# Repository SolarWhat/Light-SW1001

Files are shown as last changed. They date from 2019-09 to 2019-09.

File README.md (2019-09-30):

# Light-SW1001

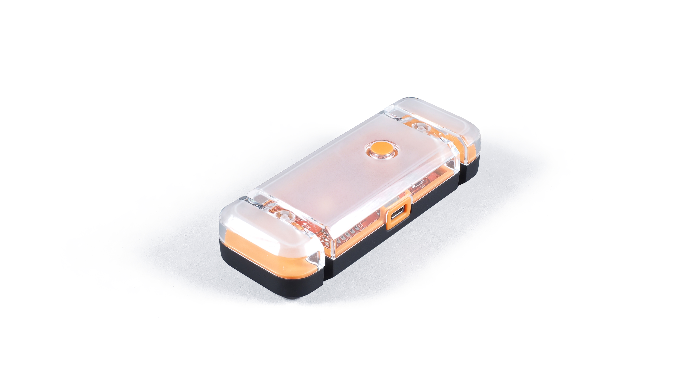
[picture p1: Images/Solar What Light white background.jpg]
Solar What Light Hero Image


Solar What?! is the outcome of ongoing research at the University of Edinburgh.

The product design process has taken place over three continents, with input from solar technicians, end users and energy access practitioners.

In 2017 over 6 million small, solar powered lighting devices were sold worldwide and 1.6 million solar powered lighting devices entered electronic waste flows.

We believe that delivering affordable, clean energy for all can also promote responsible production and consumption.

Our goal is to advocate for sustainable design in the global solar industry and promote the repair, reuse and recycling of solar powered electronics. We are pro-solar, anti-waste.

The Solar What?! Power is one of two products we have designed to champion our research and catalyse discussion around sustainability and repairability in the off-grid solar sector. The repository for our other product, the Solar What Power, can be found [here](https://github.com/SolarWhat/Power-SW2001 "here").

We encourage you to download the files, reproduce the products, make edits, suggest improvements and, most importantly, share your ideas around design for sustainable international development.  

More information about the project and the team behind it can be found on our [website](http://www.solarwhat.xyz/index.php "website").

You can get in touch with the team by emailing info@solarwhat.xyz. 

[User Manual and Tech Specs](http://www.solarwhat.xyz/resources.php "User Manual and Tech Specs")

[Gerber Files, BOM and Firmware Files](https://github.com/SolarWhat/Light-SW1001/tree/master/PCB%20Files "Gerber Files, BOM and Firmware Files")

[CAD Files (stp)](https://github.com/SolarWhat/Light-SW1001/blob/master/Solar%20What%20Light%20Assembly.stp "CAD Files (stp)")

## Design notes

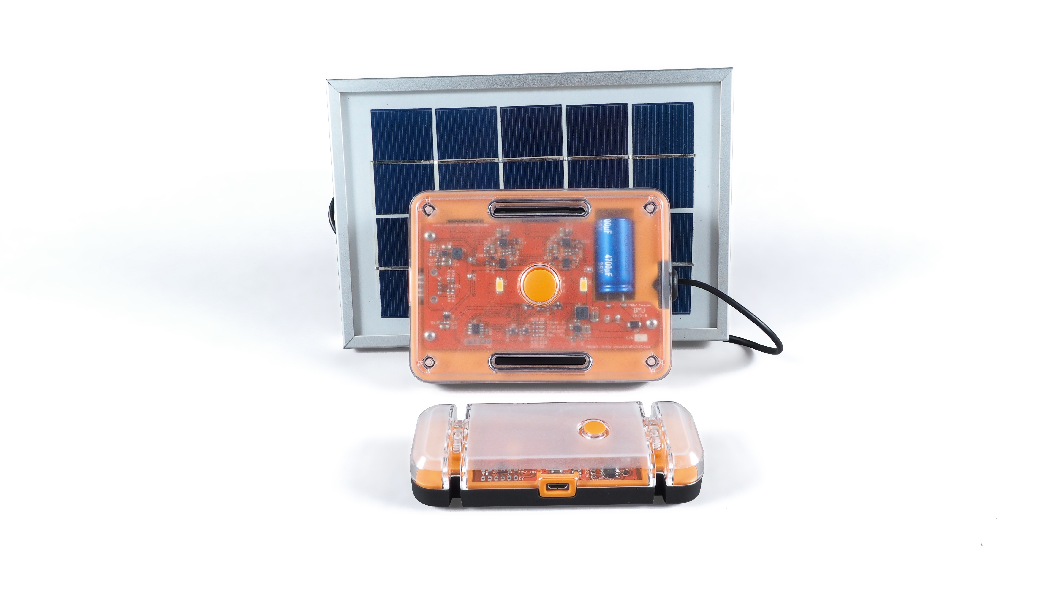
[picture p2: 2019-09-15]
Images/Solar What hero image (both).jpg

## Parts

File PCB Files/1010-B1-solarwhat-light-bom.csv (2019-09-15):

WARNING: This file is auto-generated from schematic, do not edit manually!
Component | Value | Manufacturer Part Number | Supplier Part Number | Description | Notes
C1 | 1206-10U-35V 10u 35V | 1206 10uF 35V 10% X7R | standard
C2 | 1206-10U-35V 10u 35V | 1206 10uF 35V 10% X7R | standard
C3 | 1206-10U-35V 10u 35V | 1206 10uF 35V 10% X7R | standard
C4 | 0603-100N 100n | 0603 100nF 50V 10% X7R | standard
C5 | 0603-100N 100n | 0603 100nF 50V 10% X7R | standard
D1 |  | Cree JB5630AWT-C0-0000-000A0UC430E | Farnell 2853292
D2 |  | 0603 orange | Farnell 2687484
D3 |  | 0603 green | Farnell 2687486
D4 |  | Nexperia BZX84-A3V3 | Farnell 2463632
D5 |  | 0603 red | Farnell 2687488
J1 |  | Molex 10544301-1101 | Farnell 2500017
J2 |  | AVX 009155003301006 | Digi-key 478-4687-1-ND
J3 |  | PIC-ICSP-TH-RA PIC-ICSP-TH-RA |  |  | Do not populate
J4 |  | PINHEAD-2-SQUARE PINHEAD-2-SQUARE |  |  | Do not populate
JP1 |  | SOLDER-JUMPER-1MM-SQUARE SOLDER-JUMPER-1-1 |  |  | Bridge
JP2 |  | SOLDER-JUMPER-1MM-SQUARE SOLDER-JUMPER-1-1 |  |  | Do not populate
JP3 |  | SOLDER-JUMPER-1MM-SQUARE SOLDER-JUMPER-1-1 |  |  | Do not populate
Q1 |  | Diodes Inc DMP2035U | Farnell 2061419
Q2 |  | Diodes Inc DMP2035U | Farnell 2061419
Q3 |  | Diodes Inc DMP2035U | Farnell 2061419
R1 | 0603-1%-330R 330R | 0603 330R 1% 100mW | standard
R2 | 0603-1%-330R 330R | 0603 330R 1% 100mW | standard
R3 | 0603-1%-3K9 3K9 | 0603 3K9 1% 100mW | standard
R4 | 0603-1%-22K 22K | 0603 22K 1% 100mW | standard
R5 | 0603-1%-22K 22K | 0603 22K 1% 100mW | standard
R6 | 0603-1%-100K 100K | 0603 100K 1% 100mW | standard
R7 | 0603-1%-680K 680K | 0603 680K 1% 100mW | standard
R8 | 0603-1%-1M 1M | 0603 1M 1% 100mW | standard
R9 | 0603-1%-1M 1M | 0603 1M 1% 100mW | standard
R10 | 0603-1%-100K 100K | 0603 100K 1% 100mW | standard
R11 | 0603-1%-1M 1M | 0603 1M 1% 100mW | standard
R12 | 0805-1%-17R6 17R6 | 0805 17R8 1% 100mW | Farnell 2303354
R13 | 0805-1%-1R15 1R15 | 0805 1R15 1% 100mW | Farnell 2141631
R14 | 0603-1%-20K 20K | 0603 20K 1% 100mW | standard
R15 | 0603-1%-5K23 5K23 | 0603 5K23 1% 100mW | standard
R16 | 0603-1%-7K5 7K5 | 0603 7K5 1% 100mW | standard
R17 | 0603-1%-330R 330R | 0603 330R 1% 100mW | standard
R18 | 0603-1%-330R 330R | 0603 330R 1% 100mW | standard
SW1 |  | Alcoswitch FSM4JSMA | Farnell 3801305
U1 |  | Microchip MCP73831T-2ACI/OT | Farnell 1332158
U2 |  | Maxim MAX6775XKB+T | Farnell 2799268
U3 |  | Microchip MCP1824T-ADJE/OT | Farnell 1578393
U5 |  | TI LMT87DCKR | Farnell 2782528
U6 |  | TI LM358ADR | Farnell 7527007
U7 |  | On Semi MC74VHC1GT00DF | Farnell 2724115
U8 |  | Microchip PIC12F1571-I/SN | Farnell 2419682

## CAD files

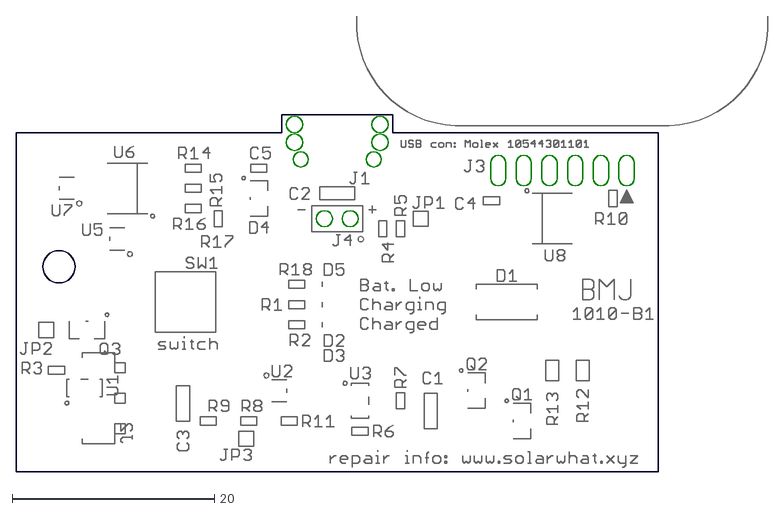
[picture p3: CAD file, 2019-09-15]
PCB Files/1010-B1-solarwhat-light-dimensions.dxf
74.3 x 45.0

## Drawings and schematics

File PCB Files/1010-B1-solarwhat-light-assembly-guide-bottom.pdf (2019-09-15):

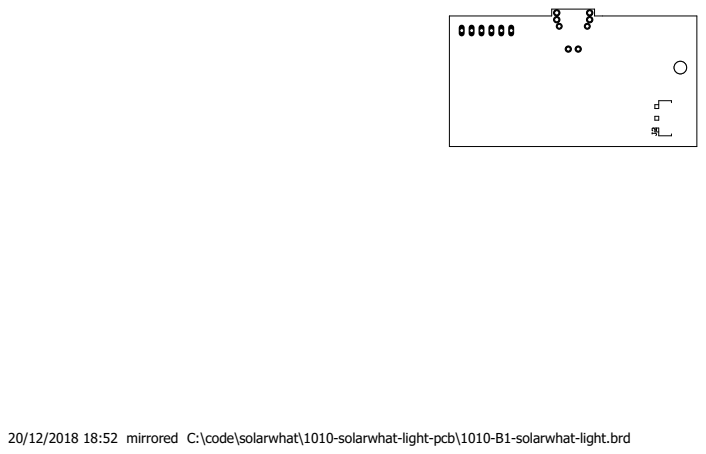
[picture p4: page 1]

20/12/2018 18:52 mirrored C:\code\solarwhat\1010-solarwhat-light-pcb\1010-B1-solarwhat-light.brd

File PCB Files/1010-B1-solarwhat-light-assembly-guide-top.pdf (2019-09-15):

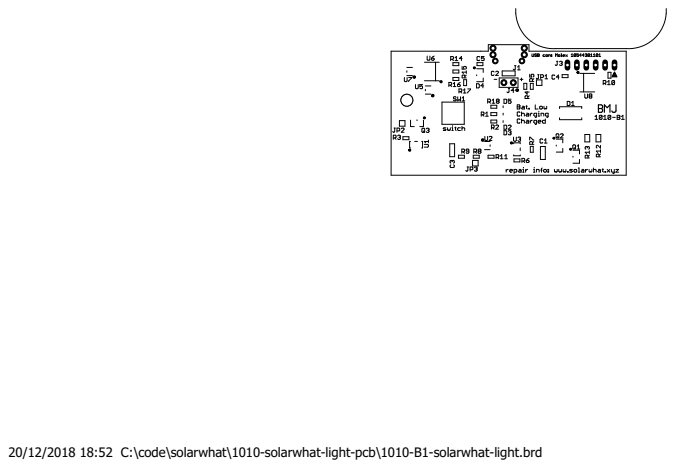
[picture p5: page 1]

20/12/2018 18:52 C:\code\solarwhat\1010-solarwhat-light-pcb\1010-B1-solarwhat-light.brd

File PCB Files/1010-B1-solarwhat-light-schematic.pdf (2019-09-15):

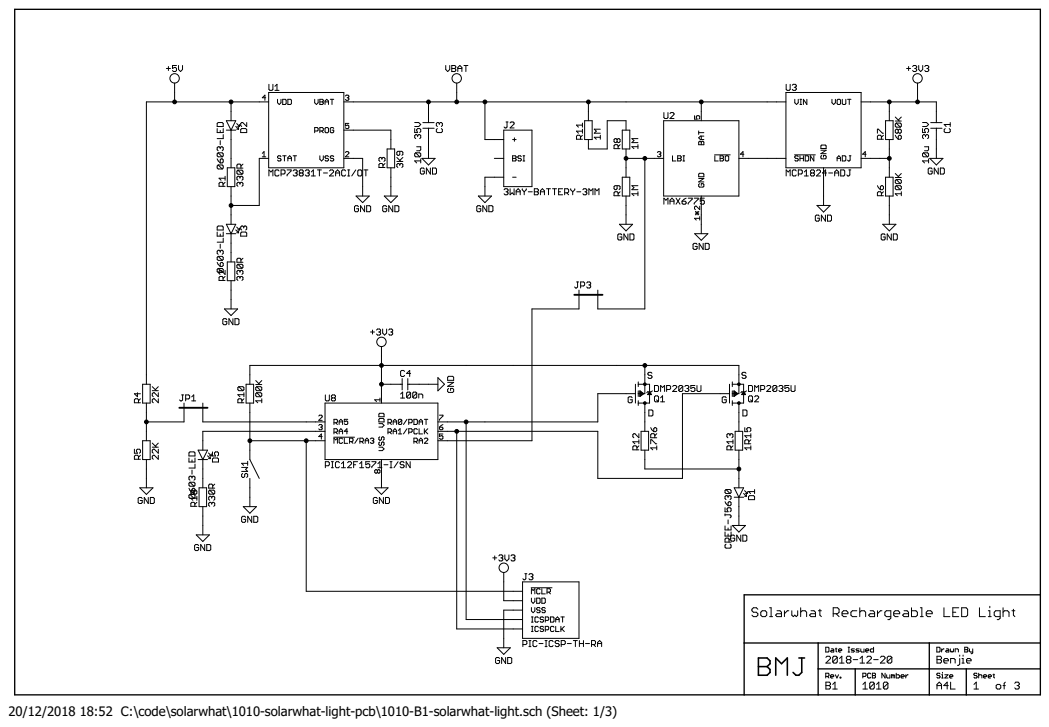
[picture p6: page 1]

20/12/2018 18:52 C:\code\solarwhat\1010-solarwhat-light-pcb\1010-B1-solarwhat-light.sch (Sheet: 1/3)

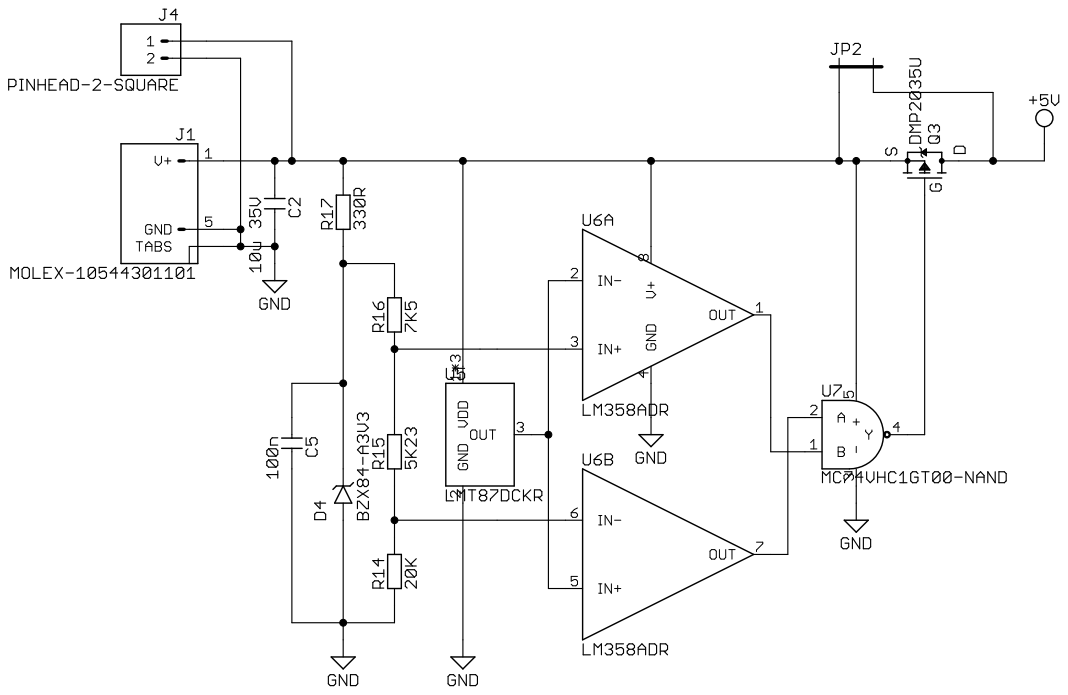
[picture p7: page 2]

20/12/2018 18:52 C:\code\solarwhat\1010-solarwhat-light-pcb\1010-B1-solarwhat-light.sch (Sheet: 2/3)

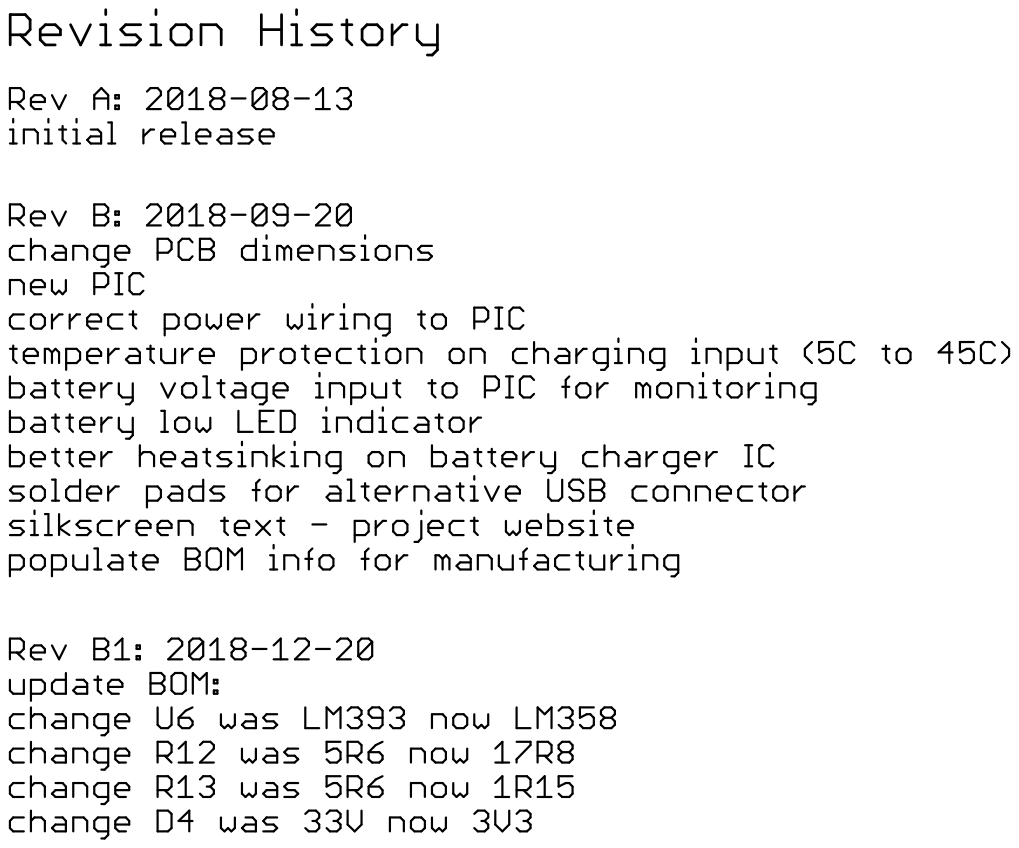
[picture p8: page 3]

20/12/2018 18:52 C:\code\solarwhat\1010-solarwhat-light-pcb\1010-B1-solarwhat-light.sch (Sheet: 3/3)

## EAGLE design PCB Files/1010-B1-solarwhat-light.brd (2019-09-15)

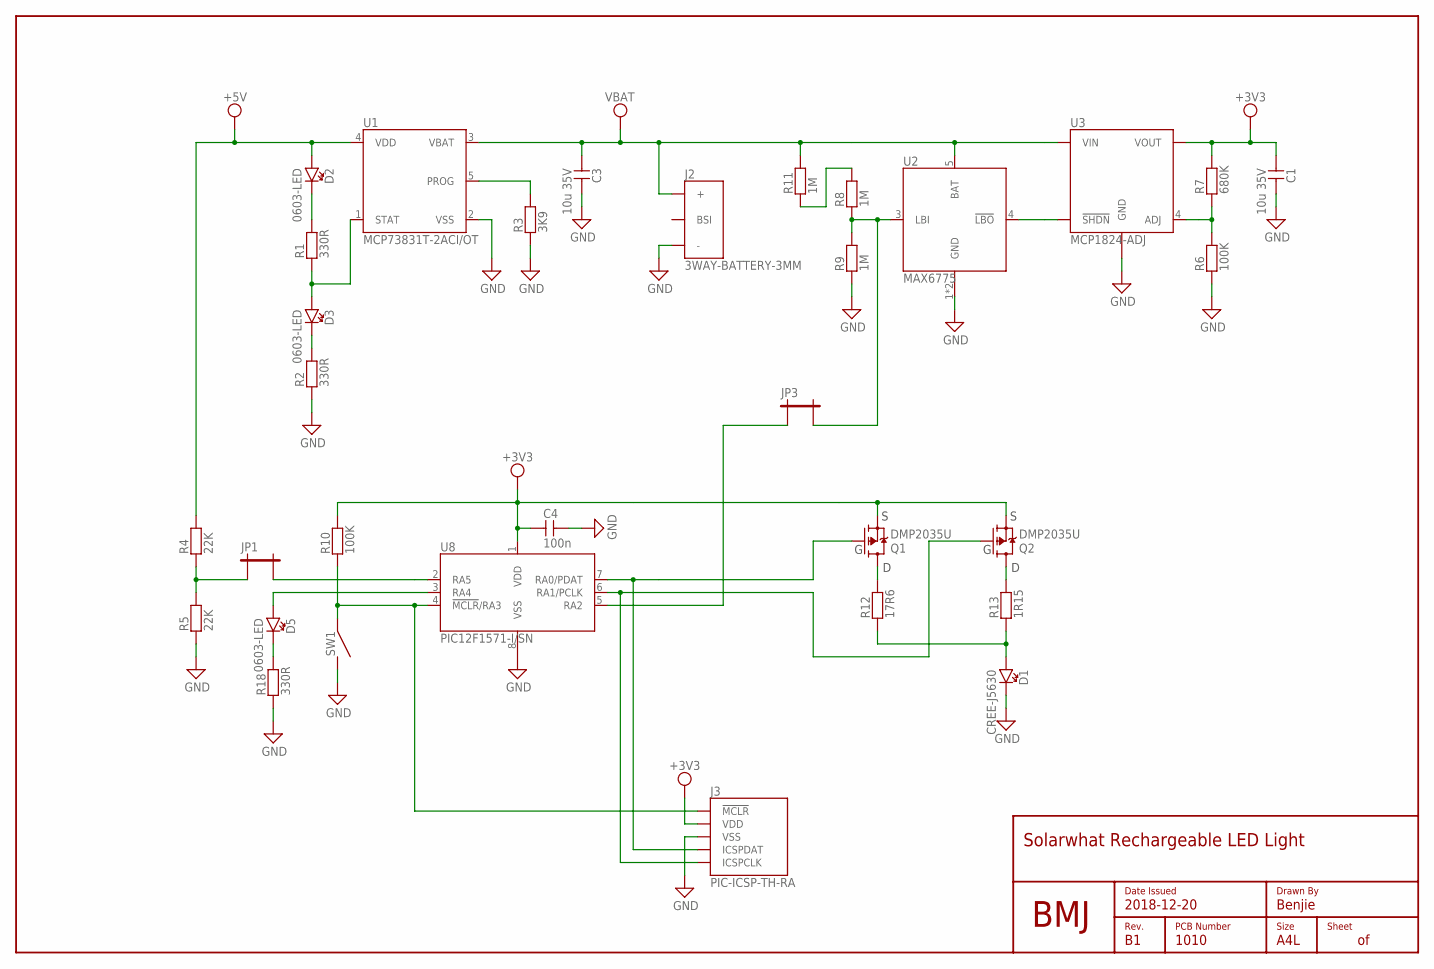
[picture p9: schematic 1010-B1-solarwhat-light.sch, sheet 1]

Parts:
C1, C3: 10u 35V; 1206
C4: 100n; 0603
D1: CREE-J5630; MPN Cree JB5630AWT-C0-0000-000A0UC430E
D2: 0603-LED; MPN 0603 orange
D3: 0603-LED; MPN 0603 green
D5: 0603-LED; MPN 0603 red
FRAME1: A4L-NEW; PCB-ID
J2: 3WAY-BATTERY-3MM; 3MM-BATTERY-3WAY
J3: PIC-ICSP-TH-RA
JP1, JP3: SOLDER-JUMPER-1MM-SQUARE; SOLDER-JUMPER-1-1
LOGO1: BMJ-LOGO
Q1, Q2: DMP2035U; SOT-23
R1, R2, R18: 330R; 0603
R3: 3K9; 0603
R4, R5: 22K; 0603
R6, R10: 100K; 0603
R7: 680K; 0603
R8, R9, R11: 1M; 0603
R12: 17R6; 0805
R13: 1R15; 0805
SW1: ALCOSWITCH-FSM4JSMA
U1: MCP73831T-2ACI/OT; SOT-23-5
U2: MAX6775; SC70
U3: MCP1824-ADJ; SOT-23-5
U8: PIC12F1571-I/SN; SOIC-8

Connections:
+3V3: C1.1, C4.1, J3.2 (VDD), Q1.2 (S), Q2.2 (S), R7.2, R10.2, U3.5 (VOUT), U8.1 (VDD)
+5V: D2.A, R4.2, U1.4 (VDD); also elsewhere on the board
GND: C1.2, C3.2, C4.2, D1.K (C), J2.-, J3.3 (VSS), R2.1, R3.1, R5.1, R6.1, R9.1, R18.1, SW1.2@1 (NO), SW1.2@2 (NO), U1.2 (VSS), U2.1 (GND), U2.2 (GND), U3.2 (GND), U8.8 (VSS); also elsewhere on the board
LED_ANODE: D1.A, R12.1, R13.1
unnamed: D3.C, R2.2
unnamed: R3.2, U1.5 (PROG)
unnamed: D3.A, R1.1, U1.1 (STAT)
unnamed: D2.C, R1.2
unnamed: JP1.1, R4.1, R5.2
unnamed: JP1.2, U8.2 (RA5)
unnamed: R6.2, R7.1, U3.4 (ADJ)
unnamed: Q2.3 (D), R13.2
unnamed: JP3.2, R8.1, R9.2, U2.3 (LBI)
unnamed: J3.5 (ICSPCLK), Q2.1 (G), U8.6 (RA1/PCLK)
unnamed: R8.2, R11.1
unnamed: Q1.3 (D), R12.2
unnamed: D5.A, U8.3 (RA4)
unnamed: U2.4 (!LBO), U3.3 (!SHDN)
unnamed: D5.C, R18.2
unnamed: J3.4 (ICSPDAT), Q1.1 (G), U8.7 (RA0/PDAT)
unnamed: J3.1 (!MCLR), R10.1, SW1.1@1 (COM), SW1.1@2 (COM), U8.4 (!MCLR!/RA3)
unnamed: JP3.1, U8.5 (RA2)
VBAT: C3.1, J2.+, R11.2, U1.3 (VBAT), U2.5 (BAT), U3.1 (VIN)

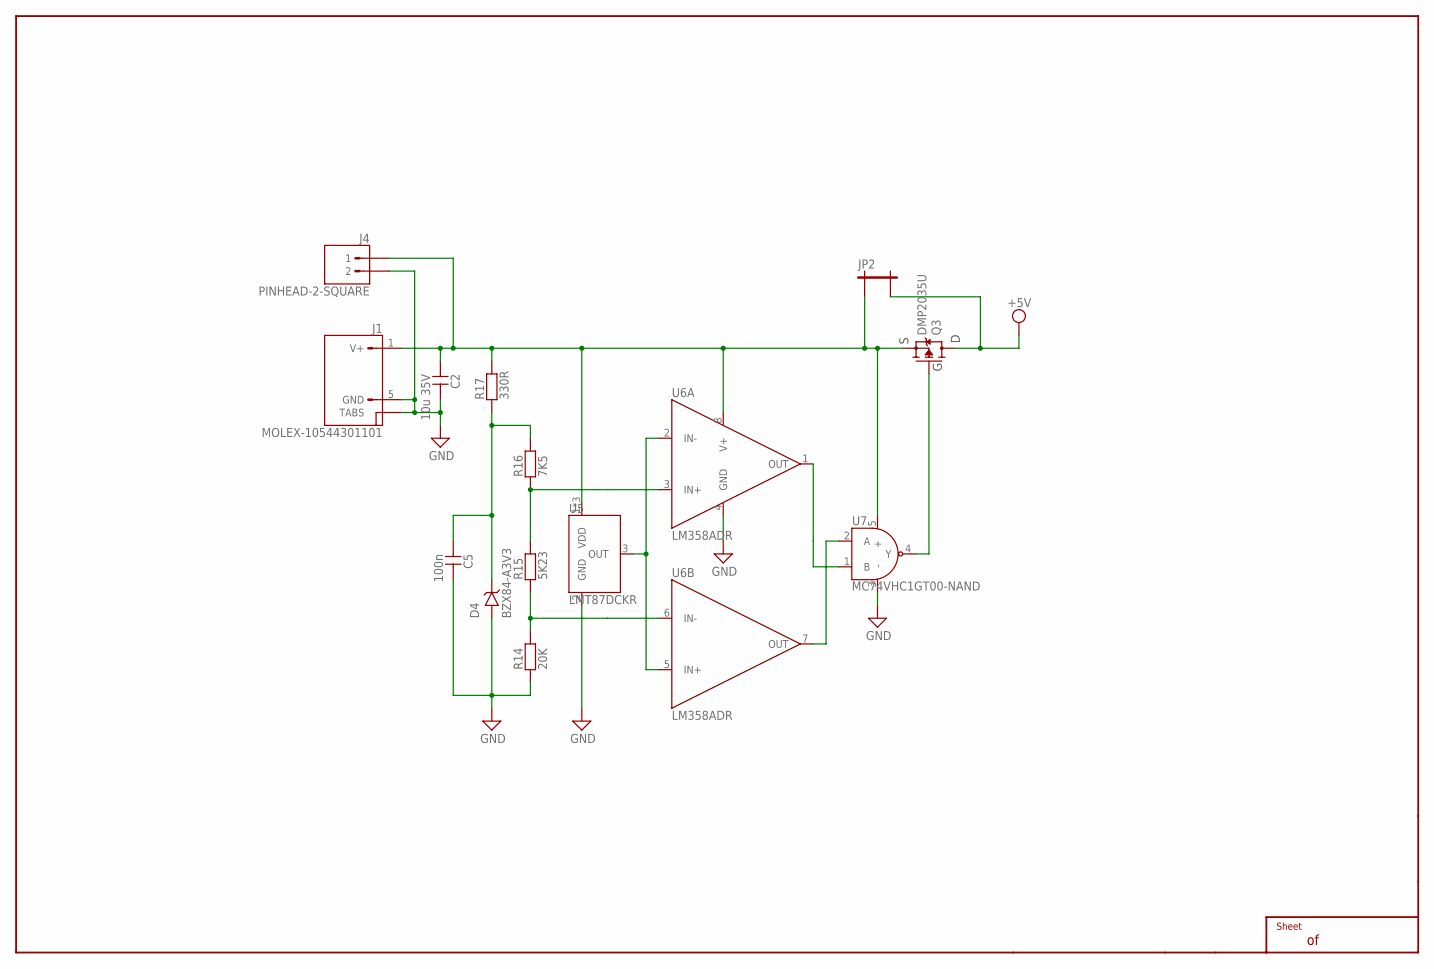
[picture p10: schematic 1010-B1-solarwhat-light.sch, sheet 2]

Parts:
C2: 10u 35V; 1206
C5: 100n; 0603
D4: BZX84-A3V3; SOT-23
FRAME2: A4L-CONTINUATION; EMPTY
J1: MOLEX-10544301101; MOLEX-105443-1101-POWERONLY; MPN Molex 10544301-1101
J4: PINHEAD-2-SQUARE
JP2: SOLDER-JUMPER-1MM-SQUARE; SOLDER-JUMPER-1-1
Q3: DMP2035U; SOT-23
R14: 20K; 0603
R15: 5K23; 0603
R16: 7K5; 0603
R17: 330R; 0603
U5: LMT87DCKR; SC70
U6: LM358ADR; SOIC-8
U7: MC74VHC1GT00-NAND; SC70

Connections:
+5V: JP2.2, Q3.3 (D); also elsewhere on the board
GND: C2.2, C5.2, D4.1 (A), J1.5 (GND), J1.GND@1 (TABS), J1.GND@2 (TABS), J1.GND@3 (TABS), J1.GND@4 (TABS), J1.GND@5 (TABS), J1.GND@6 (TABS), J4.2, R14.1, U5.2 (GND), U6.4 (GND), U7.3 (-); also elsewhere on the board
unnamed: C2.1, J1.1 (V+), J4.1, JP2.1, Q3.2 (S), R17.2, U5.1 (VDD), U5.4 (VDD), U5.5 (VDD), U6.8 (V+), U7.5 (+)
unnamed: U6.1 (OUT), U7.1 (B)
unnamed: U6.7 (OUT), U7.2 (A)
unnamed: Q3.1 (G), U7.4 (Y)
unnamed: U5.3 (OUT), U6.2 (IN-), U6.5 (IN+)
unnamed: R14.2, R15.1, U6.6 (IN-)
unnamed: R15.2, R16.1, U6.3 (IN+)
unnamed: C5.1, D4.3 (K), R16.2, R17.1

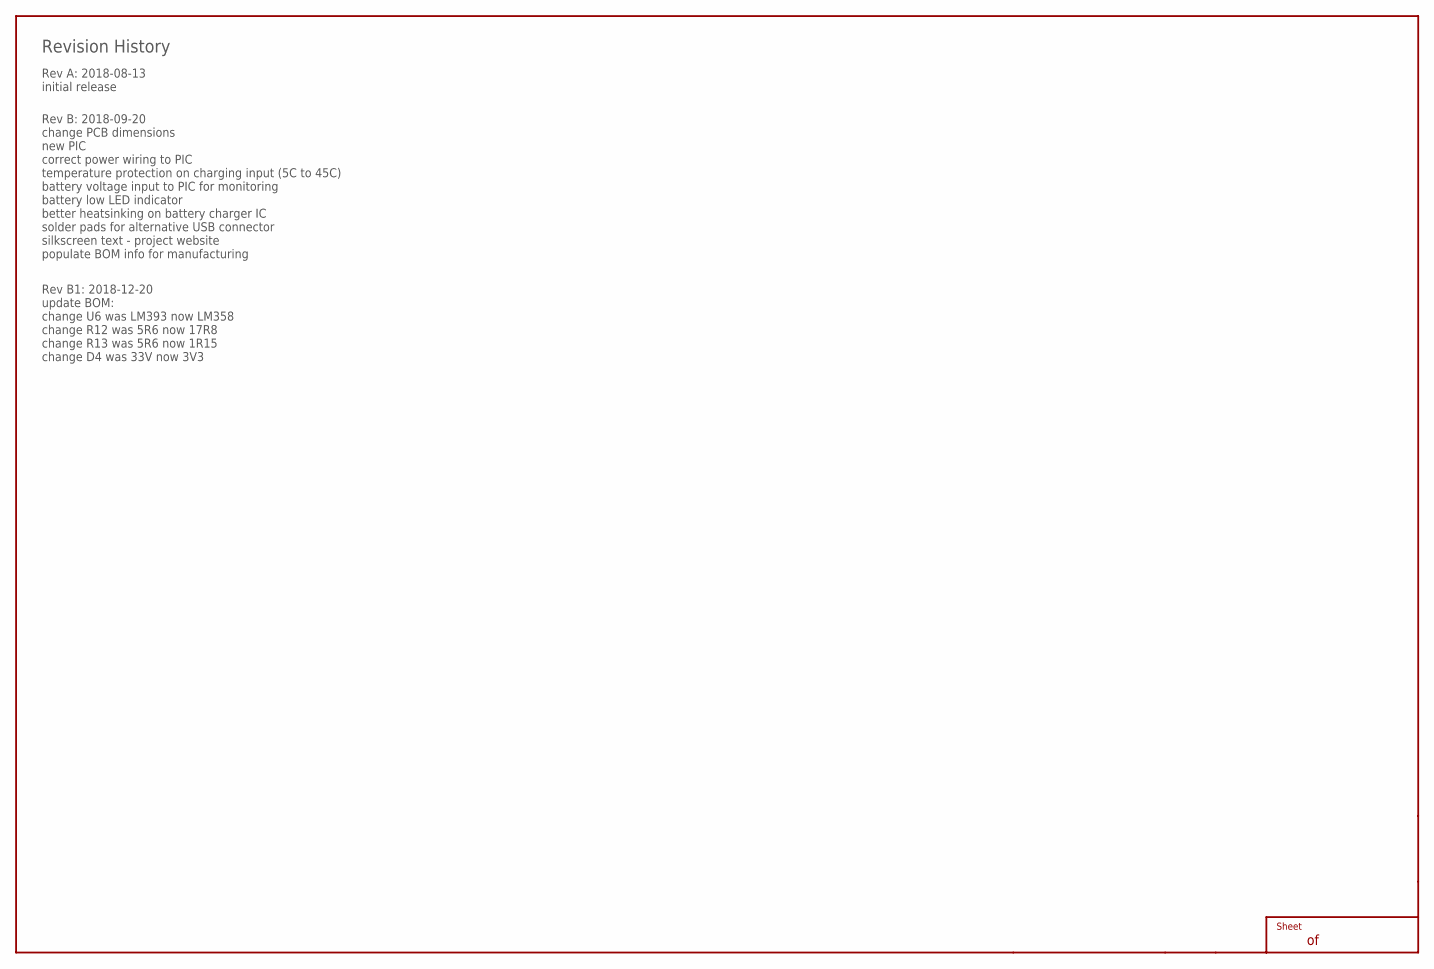
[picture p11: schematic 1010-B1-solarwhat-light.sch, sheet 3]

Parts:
FRAME3: A4L-CONTINUATION; EMPTY

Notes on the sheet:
Revision History
Rev A: 2018-08-13 initial release
Rev B: 2018-09-20 change PCB dimensions new PIC correct power wiring to PIC temperature protection on charging input (5C to 45C) battery voltage input to PIC for monitoring battery low LED indicator better heatsinking on battery charger IC solder pads for alternative USB connector silkscreen text -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
Rev B1: 2018-12-20 update BOM: change U6 was LM393 now LM358 change R12 was 5R6 now 17R8 change R13 was 5R6 now 1R15 change D4 was 33V now 3V3

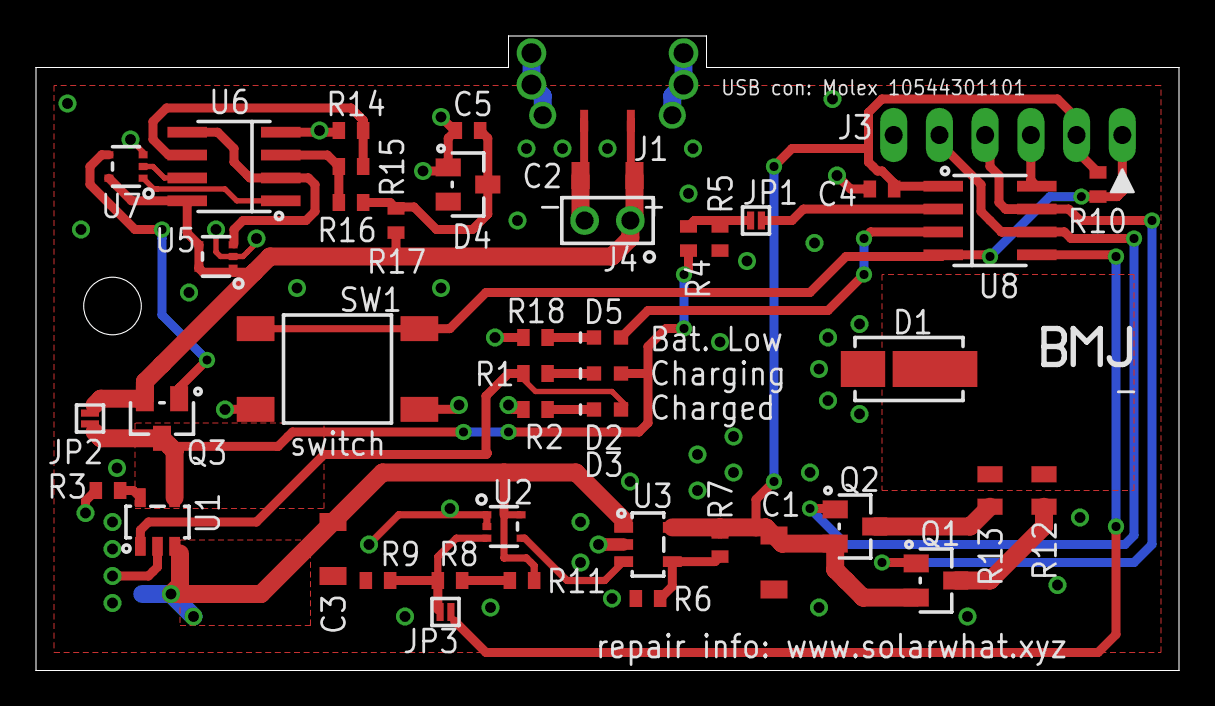
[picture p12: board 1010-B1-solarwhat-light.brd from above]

Board: 2 copper layers, 63.5 x 35.2 mm, 50 parts (1 on the bottom side), 31 nets.

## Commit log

2019-09-15 Added PCB files
    Gerbers, bom etc
    [1010-B1-solarwhat-light-bom.csv, 1010-B1-solarwhat-light-dimensions.dxf, 1010-B1-solarwhat-light.brd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]
2019-09-15 Cad files uploaded
2019-09-30 Readme: Fixing broken link to SW Power repo
